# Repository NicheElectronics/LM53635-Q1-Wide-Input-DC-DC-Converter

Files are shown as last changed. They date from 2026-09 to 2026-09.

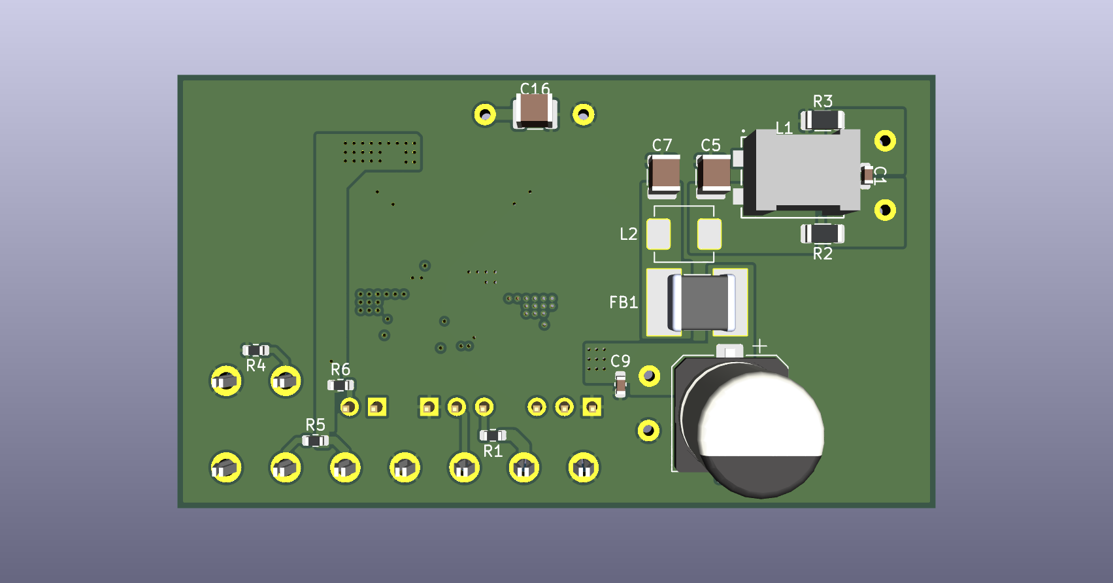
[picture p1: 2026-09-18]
pcb-design/renders/PCB-3D-Bottom.png

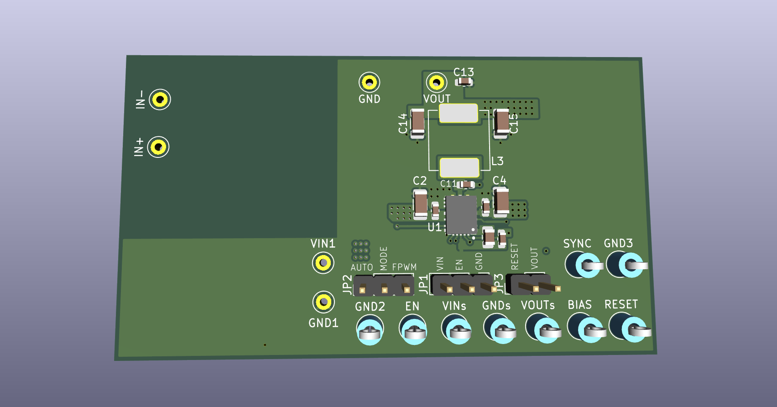
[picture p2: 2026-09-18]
pcb-design/renders/PCB-3D-Top.png

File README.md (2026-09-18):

# LM53635-Q1 Wide-Input DC-DC Converter

A four-layer, **5 V / 3.5 A design-target** synchronous buck converter built around the Texas Instruments **LM53635-Q1**. The board is intended for a **6–36 V input** and provides a choice of direct or EMI-filtered input paths for evaluating power-supply behavior.

> **Status:** PCB design and PSpice simulation are complete. The board has not yet been fabricated or electrically validated. The voltage, current, efficiency and EMI performance described here are design goals, not measured results.

## At a glance

| Item | Design |
| --- | --- |
| Controller | TI LM53635-Q1 automotive synchronous step-down converter |
| Intended input | 6–36 V DC |
| Intended output | 5 V, up to 3.5 A design target |
| PCB | Four layers, designed in KiCad |
| Input options | Direct path and EMI-filtered path |
| Analysis | PSpice startup and steady-state/transient simulations |
| Hardware verification | Pending fabrication and bench measurements |

The **6–36 V** range is this board's intended range. The IC's own operating limits and transient ratings are specified in the [TI LM53635-Q1 datasheet](https://www.ti.com/product/LM53635-Q1); they should not be treated as a measured rating of the assembled board.

## Design overview

```mermaid
flowchart LR
    VIN["6–36 V input"] --> PATH["Direct or filtered input"]
    PATH --> BUCK["LM53635-Q1 buck stage"]
    BUCK --> OUT["5 V output"]
```

The layout emphasizes a compact switching-current loop, local decoupling, sensible AGND/GND handling, input filtering and accessible measurement points. The filtered and direct input options support comparison during later EMI and transient testing. The project files include KiCad hardware data, manufacturing outputs, board renders and PSpice work; consult those source files for exact component values and connector pinouts.

## Simulation and validation

Startup and transient behavior have been examined in **PSpice for TI**. Simulation helps check the design before fabrication but does not establish hardware output ripple, efficiency, thermal behavior or emissions.

Once a board is assembled, the planned checks are:

1. Inspect assembly, polarity and resistance between each power rail and ground.
2. Power the board from a current-limited bench supply and verify the 5 V output at light load.
3. Check startup and output regulation across the intended input range and representative loads.
4. Measure ripple, load-transient response and component temperature; record the instruments and test conditions.
5. Compare direct and filtered input paths and evaluate conducted EMI with a suitable measurement setup.

No bench measurements or compliance results are claimed at this stage.

## Design files and reference

The repository contains the schematic, PCB design, manufacturing material, renders and simulation results. Use the **KiCad source files** as the authority for the actual revision and the [TI datasheet](https://www.ti.com/product/LM53635-Q1) for device limits and recommended layout practice.

## Author

**Nishant Patil**

No license has been specified for the project files. Add one if you want to define reuse terms.

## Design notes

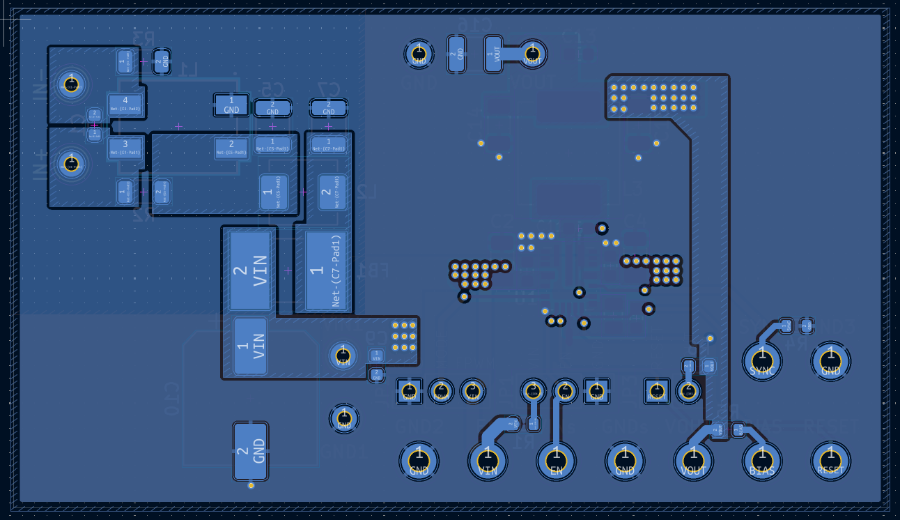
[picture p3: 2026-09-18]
pcb-design/layers/L4-Bottom-Power-Signal-GND-Pour.png

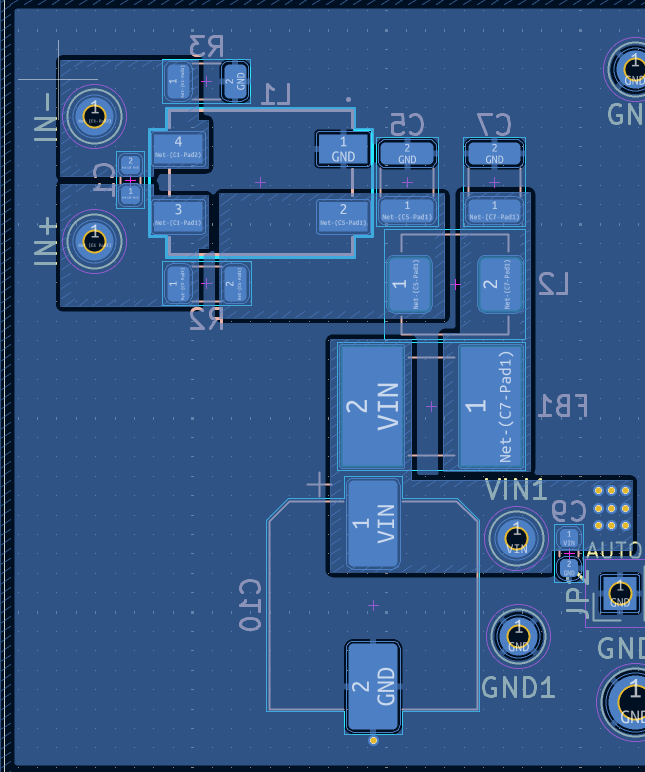
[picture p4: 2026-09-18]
pcb-design/emi-filter/EMI-Filter-PCB-Implementation.png

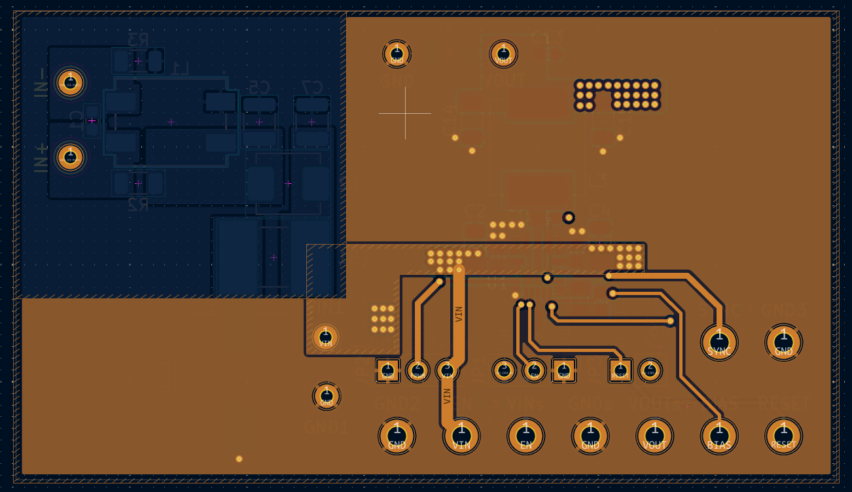
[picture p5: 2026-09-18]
pcb-design/layers/L3-Power-Signal-GND-Pour.png

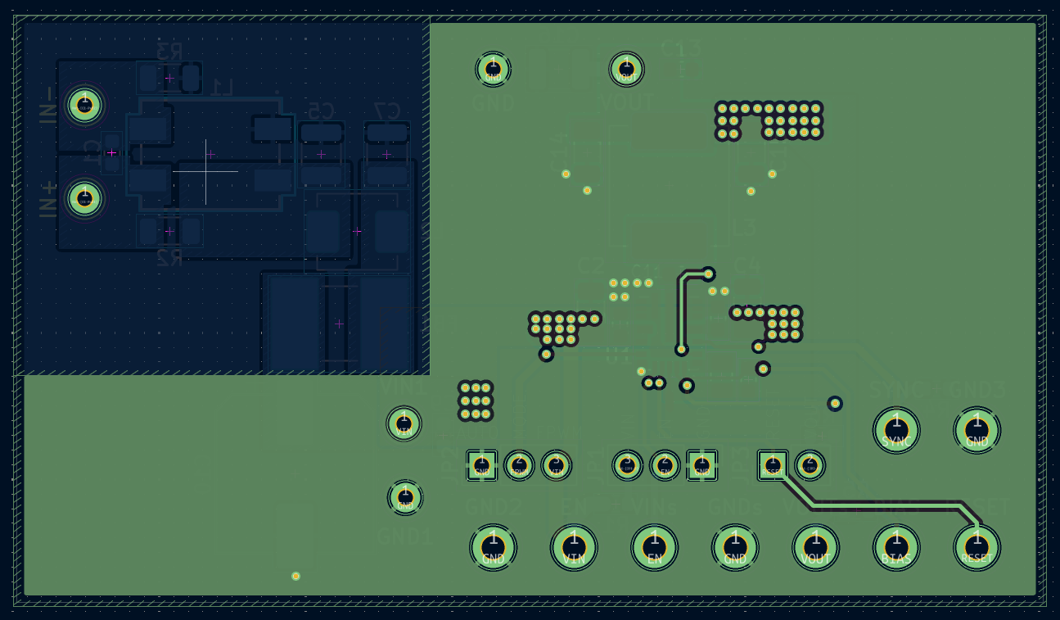
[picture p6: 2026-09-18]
pcb-design/layers/L2-GND-Plane-Local-Signals.png

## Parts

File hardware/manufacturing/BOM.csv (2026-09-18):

Reference | Qty | Value | DNP | Exclude from BOM | Exclude from Board | Footprint | Datasheet
BIAS1,EN1,GND2,GND3,GNDs1,RESET1,SYNC1,VINs1,VOUTs1 | 9 | TestPoint |  |  |  | TestPoint:TestPoint_Keystone_5005-5009_Compact | ~
C1,C9,C12,C13 | 4 | 0.1uF |  |  |  | Capacitor_SMD:C_0603_1608Metric | ~
C2,C4 | 2 | 10uF |  |  |  | Capacitor_SMD:C_1206_3216Metric | ~
C3,C6 | 2 | 0.047uF |  |  |  | Capacitor_SMD:C_0603_1608Metric | ~
C5,C7 | 2 | 4.7uF |  |  |  | Capacitor_SMD:C_1210_3225Metric | ~
C8 | 1 | 4.7uF |  |  |  | Capacitor_SMD:C_0805_2012Metric | ~
C10 | 1 | 100uF |  |  |  | Capacitor_SMD:CP_Elec_10x10.5
C11 | 1 | 0.47uF |  |  |  | Capacitor_SMD:C_0603_1608Metric | ~
C14,C15 | 2 | 22uF |  |  |  | Capacitor_SMD:C_1206_3216Metric | ~
C16 | 1 | 47uF |  |  |  | Capacitor_SMD:C_1210_3225Metric | ~
FB1 | 1 | 600 ohm |  |  |  | HI2220P601R-10:FB_HI2220P601R-10 | ~
GND1,GND4,IN+1,IN-1,VIN1,VOUT1 | 6 | TestPoint |  |  |  | TestPoint:TestPoint_Keystone_5000-5004_Miniature | ~
JP1 | 1 | EN Jumper |  | Excluded from BOM |  | Connector_PinHeader_2.54mm:PinHeader_1x03_P2.54mm_Vertical | ~
JP2 | 1 | FPWM Jumper |  | Excluded from BOM |  | Connector_PinHeader_2.54mm:PinHeader_1x03_P2.54mm_Vertical | ~
JP3 | 1 | Reset Jumper |  |  |  | Connector_PinHeader_2.54mm:PinHeader_1x02_P2.54mm_Vertical | ~
L1 | 1 | ACM9070-701-2PL-TL01 |  |  |  | ACM9070-701-2PL-TL01:IND_ACM9070_TDK | ACM9070-701-2PL-TL01
L2 | 1 | 2.2uH |  |  |  | IHLP2020CZER2R2M11:INDM5451X300N | ~
L3 | 1 | 2.2uH |  |  |  | IHLP3232DZER2R2M11:INDM8681X400N | ~
NT1 | 1 | NetTie_2 |  | Excluded from BOM |  | NetTie:NetTie-2_SMD_Pad0.5mm | ~
R1,R4,R6 | 3 | 100K |  |  |  | Resistor_SMD:R_0603_1608Metric | ~
R2,R3 | 2 | 0R |  |  |  | Resistor_SMD:R_1206_3216Metric | ~
R5 | 1 | 3R |  |  |  | Resistor_SMD:R_0603_1608Metric | ~
U1 | 1 | LM536353QRNLRQ1 |  |  |  | LM53635LQRNLTQ1:CONV_LMS3655MMRNLR | https://www.ti.com/lit/gpn/lm53635-q1

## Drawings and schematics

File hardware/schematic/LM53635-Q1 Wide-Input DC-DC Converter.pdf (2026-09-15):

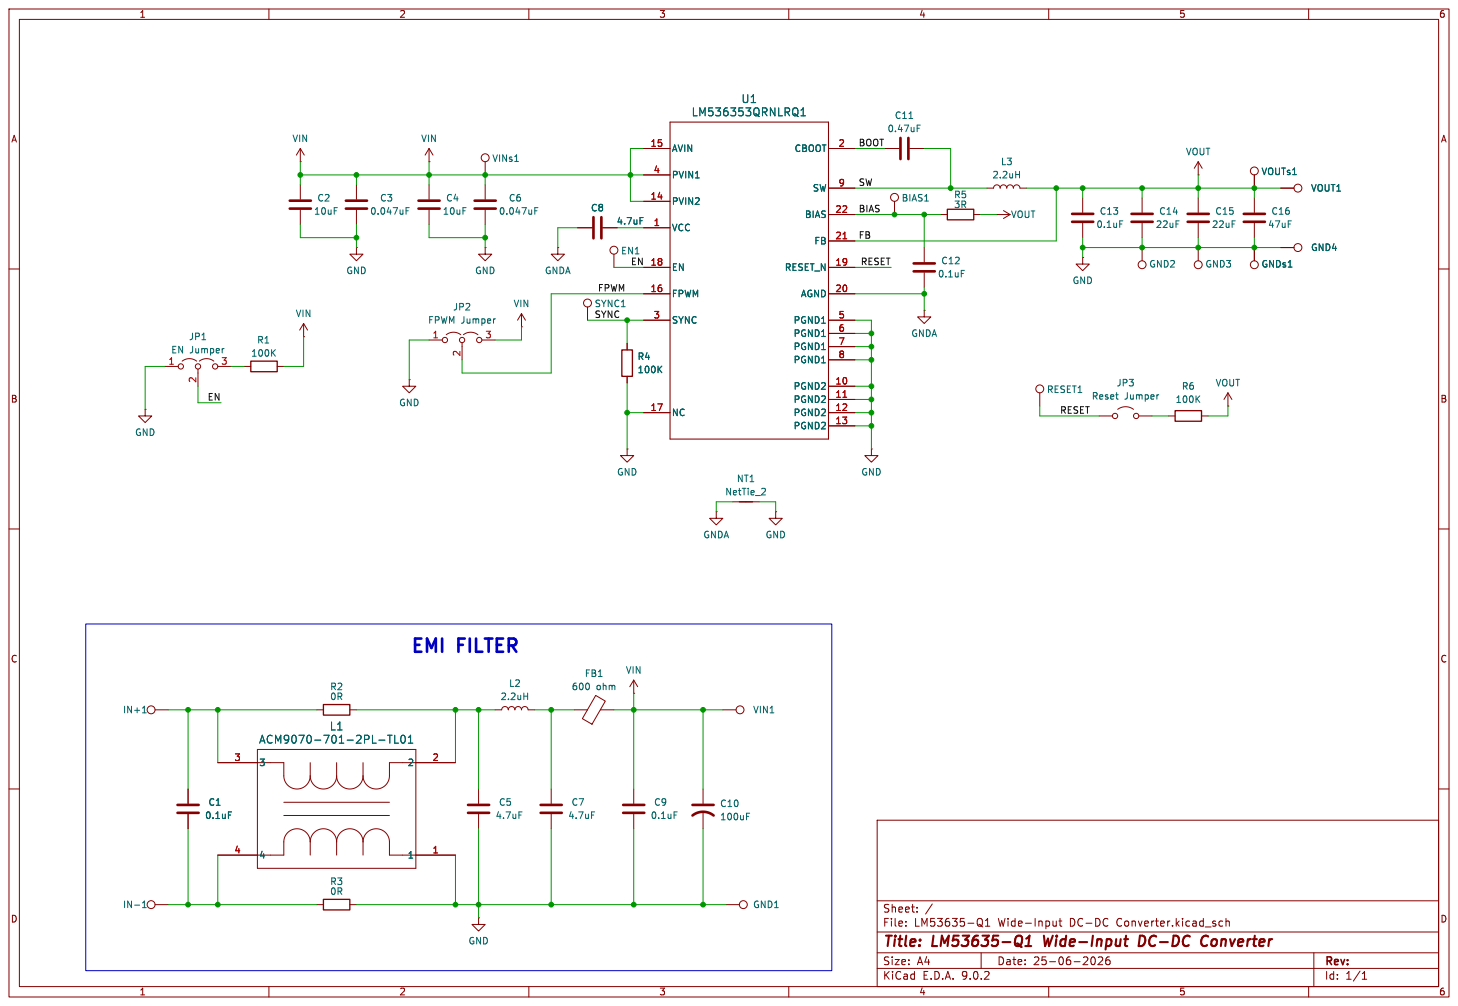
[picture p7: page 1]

BOOT SW EMI FILTER

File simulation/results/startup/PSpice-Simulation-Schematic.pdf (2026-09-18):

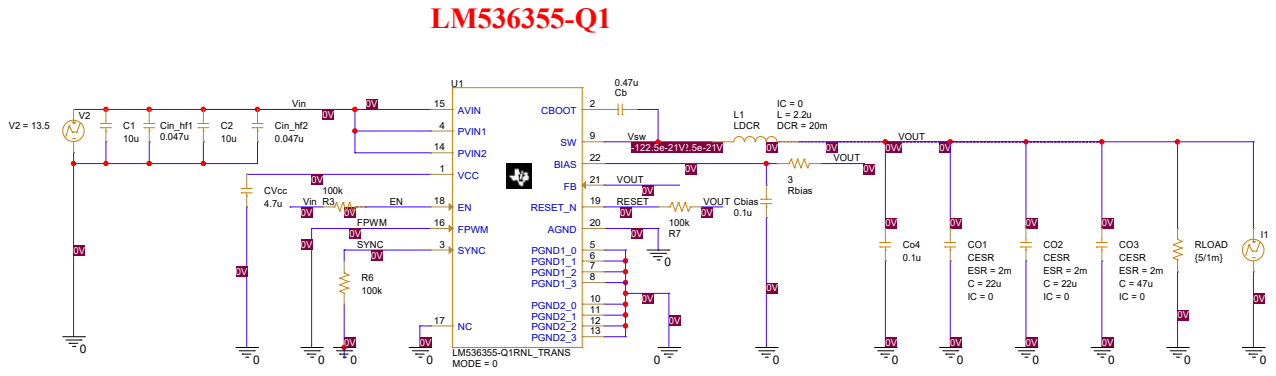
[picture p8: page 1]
FPWM 0V; SYNC 0V; Vsw -122.5e-21V; VOUT 0V; VOUT; Vin; RESET; Vin 0V; CO1 CESR; ESR = 2m C = 22u; Rbias 3 CVcc 4.7u; RLOAD; LM536355-Q1RNL_TRANS MODE = 0 VCC 1; CBOOT; 2 SYNC 3; PVIN1 4; PGND1_0; 5 PGND1_1; 6 PGND1_2; 7 PGND1_3; 9 PGND2_0; 10 PGND2_1; 11 PGND2_2; 12 PGND2_3; 13 PVIN2 14; AVIN 15; FPWM 16; RESET_N; 19 AGND; 21 BIAS; CO3 CESR; ESR = 2m C = 47u IC = 0; I1 Cin_hf1; CO2 CESR; IC = 0 Cbias 0.1u C2; Cin_hf2; L1 LDCR; L = 2.2u DCR = 20m

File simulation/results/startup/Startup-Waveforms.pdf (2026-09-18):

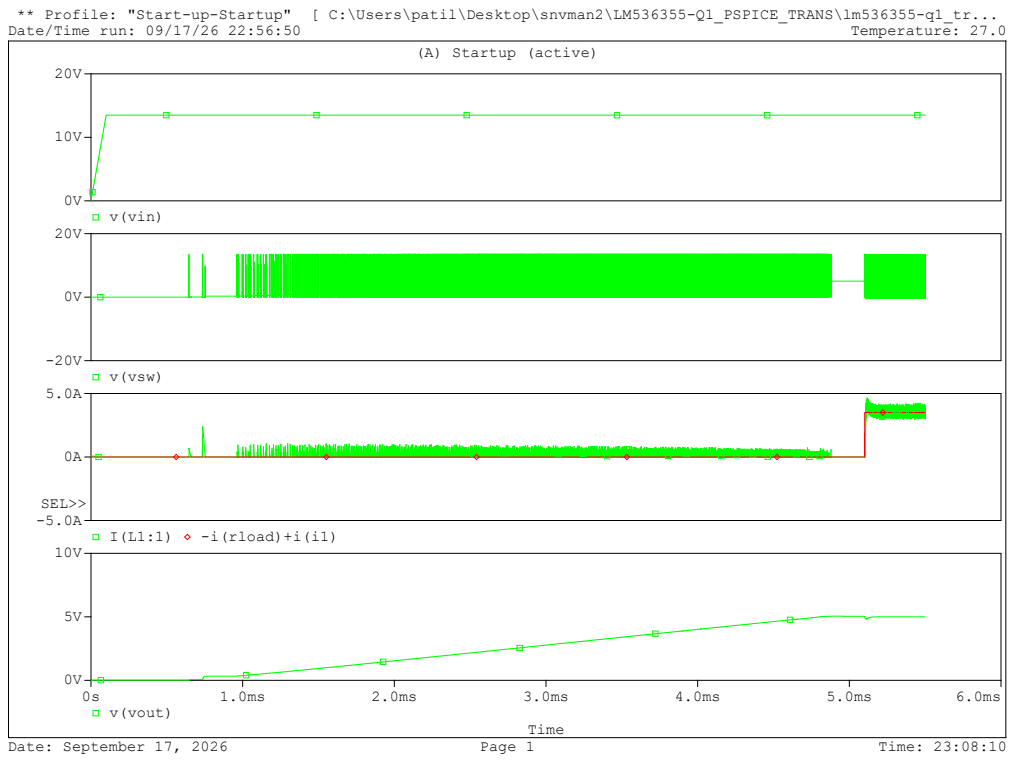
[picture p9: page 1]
Temperature: 27.0; Date: September 17, 2026; Page 1; Time: 23:08:10; (A) Startup (active); Time; v(vout); -i(rload)+i(i1); SEL>>; v(vsw); v(vin)

** Profile: "Start-up-Startup" [ C:\Users\patil\Desktop\snvman2\LM536355-Q1_PSPICE_TRANS\lm536355-q1_tr...
Date/Time run: 09/17/26 22:56:50

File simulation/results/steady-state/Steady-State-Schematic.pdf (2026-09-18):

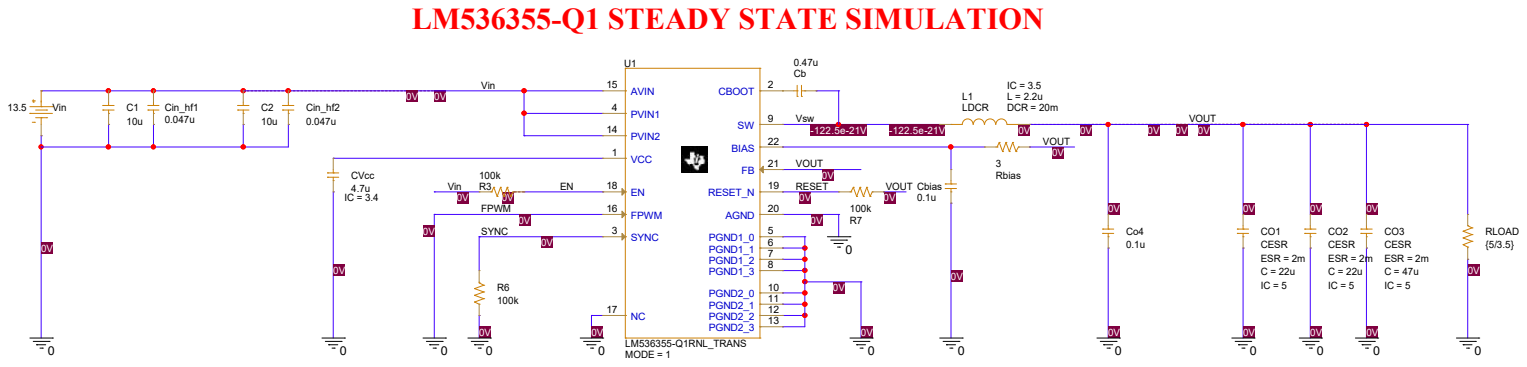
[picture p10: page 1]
FPWM; SYNC; Vsw -122.5e-21V; VOUT 0V; VOUT; 0V RESET 0V; Vin; Vin 0V; LM536355-Q1 STEADY STATE SIMULATION; CO1 CESR; ESR = 2m C = 22u; IC = 5 Cbias 0.1u Cin_hf1; LM536355-Q1RNL_TRANS MODE = 1 VCC 1; CBOOT; 2 SYNC 3; PVIN1 4; PGND1_0; 5 PGND1_1; 6 PGND1_2; 7 PGND1_3; 9 PGND2_0; 10 PGND2_1; 11 PGND2_2; 12 PGND2_3; 13 PVIN2 14; AVIN 15; FPWM 16; RESET_N; 19 AGND; 21 BIAS; Rbias 3 C1; CO2 CESR; 100k Cin_hf2; CVcc 4.7u; CO3 CESR; ESR = 2m C = 47u; LDCR; L = 2.2u DCR = 20m; RLOAD

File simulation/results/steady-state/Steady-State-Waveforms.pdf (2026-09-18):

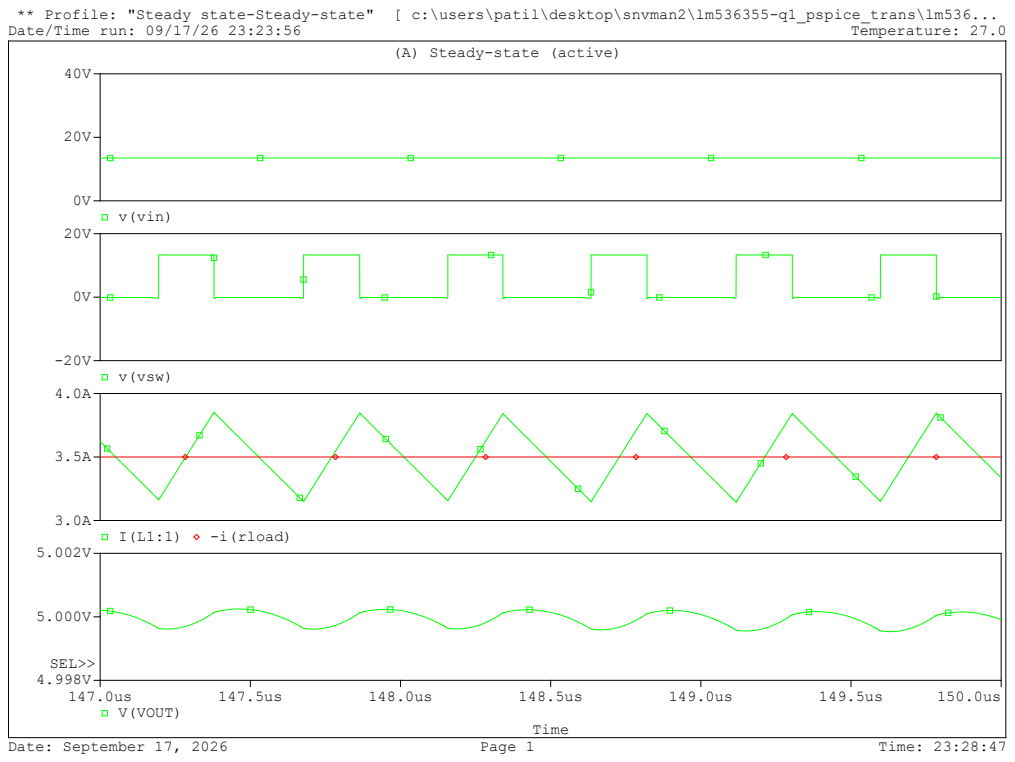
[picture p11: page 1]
Temperature: 27.0; Date: September 17, 2026; Page 1; Time: 23:28:47; Time; V(VOUT); SEL>>; -i(rload); v(vsw); v(vin)

** Profile: "Steady state-Steady-state" [ c:\users\patil\desktop\snvman2\lm536355-q1_pspice_trans\lm536...
Date/Time run: 09/17/26 23:23:56

(A) Steady-state (active)

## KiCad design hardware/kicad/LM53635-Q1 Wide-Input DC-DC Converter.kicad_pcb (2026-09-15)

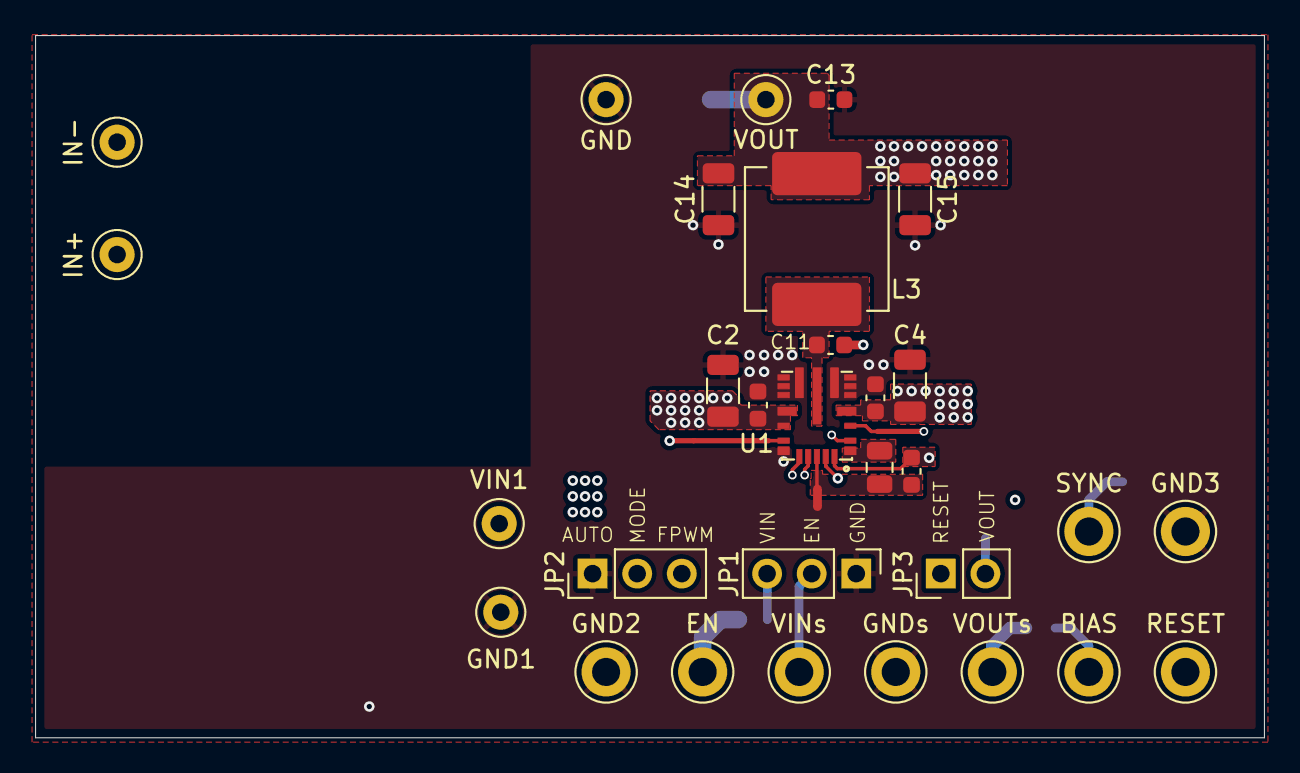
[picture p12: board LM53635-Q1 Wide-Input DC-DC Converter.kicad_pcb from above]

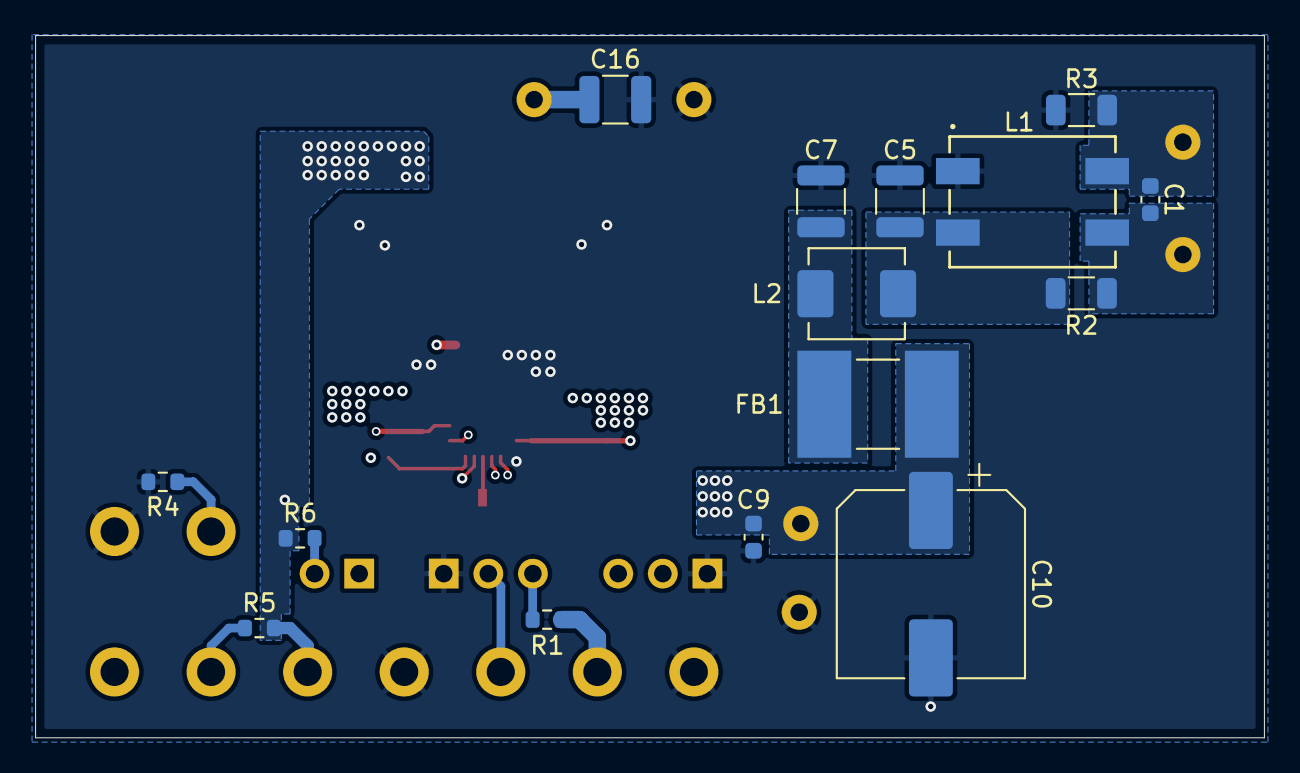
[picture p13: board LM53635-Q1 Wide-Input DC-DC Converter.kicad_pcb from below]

Board: 4 copper layers, 70.0 x 40.0 mm, 46 parts (15 on the bottom side), 18 nets.

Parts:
BIAS: TestPoint; TestPoint_Keystone_5005-5009_Compact
C1, C9, C12, C13: 0.1uF; C_0603_1608Metric
C2, C4: 10uF; C_1206_3216Metric
C3, C6: 0.047uF; C_0603_1608Metric
C5, C7: 4.7uF; C_1210_3225Metric
C8: 4.7uF; C_0805_2012Metric
C10: 100uF; CP_Elec_10x10.5
C11: 0.47uF; C_0603_1608Metric
C14, C15: 22uF; C_1206_3216Metric
C16: 47uF; C_1210_3225Metric
EN: TestPoint; TestPoint_Keystone_5005-5009_Compact
FB1: 600 ohm; FB_HI2220P601R-10
GND, GND1: TestPoint; TestPoint_Keystone_5000-5004_Miniature
GND2, GND3: TestPoint; TestPoint_Keystone_5005-5009_Compact
GNDs: TestPoint; TestPoint_Keystone_5005-5009_Compact
IN+: TestPoint; TestPoint_Keystone_5000-5004_Miniature
IN-: TestPoint; TestPoint_Keystone_5000-5004_Miniature
JP1: EN Jumper; PinHeader_1x03_P2.54mm_Vertical
JP2: FPWM Jumper; PinHeader_1x03_P2.54mm_Vertical
JP3: Reset Jumper; PinHeader_1x02_P2.54mm_Vertical
L1: ACM9070-701-2PL-TL01; IND_ACM9070_TDK
L2: 2.2uH; INDM5451X300N
L3: 2.2uH; INDM8681X400N
NT1: NetTie_2; NetTie-2_SMD_Pad0.5mm
R1, R4, R6: 100K; R_0603_1608Metric
R2, R3: 0R; R_1206_3216Metric
R5: 3R; R_0603_1608Metric
RESET: TestPoint; TestPoint_Keystone_5005-5009_Compact
SYNC: TestPoint; TestPoint_Keystone_5005-5009_Compact
U1: LM536353QRNLRQ1; CONV_LMS3655MMRNLR
VIN1: TestPoint; TestPoint_Keystone_5000-5004_Miniature
VINs: TestPoint; TestPoint_Keystone_5005-5009_Compact
VOUT: TestPoint; TestPoint_Keystone_5000-5004_Miniature
VOUTs: TestPoint; TestPoint_Keystone_5005-5009_Compact

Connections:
/BIAS: BIAS.1, C12.1, R5.1, U1.22 (BIAS)
/BOOT: C11.1, U1.2 (CBOOT)
/EN: JP1.2 (C), U1.18 (EN), VINs.1
/FPWM: JP2.2 (C), U1.16 (FPWM)
/RESET: JP3.1 (A), RESET.1, U1.19 (RESET_N)
/SW: C11.2, L3.1, U1.9 (SW)
/SYNC: R4.1, SYNC.1, U1.3 (SYNC)
GND: C2.2, C3.2, C4.2, C5.2, C6.2, C7.2, C9.2, C10.2, C13.2, C14.2, C15.2, C16.2, GND.1, GND1.1, GND2.1, GND3.1, GNDs.1, JP1.1 (A), JP2.1 (A), L1.1, NT1.2, R3.2, R4.2, U1.5 (PGND1), U1.6 (PGND1), U1.7 (PGND1), U1.8 (PGND1), U1.10 (PGND2), U1.11 (PGND2), U1.12 (PGND2), U1.13 (PGND2), U1.17 (NC)
GNDA: C8.1, C12.2, NT1.1, U1.20 (AGND)
unnamed: C1.1, IN+.1, L1.3, R2.1
unnamed: C1.2, IN-.1, L1.4, R3.1
unnamed: C5.1, L1.2, L2.1, R2.2
unnamed: C7.1, FB1.1, L2.2
unnamed: JP1.3 (B), R1.1
unnamed: JP3.2 (B), R6.2
unnamed: C8.2, U1.1 (VCC)
VIN: C2.1, C3.1, C4.1, C6.1, C9.1, C10.1, EN.1, FB1.2, JP2.3 (B), R1.2, U1.4 (PVIN1), U1.14 (PVIN2), U1.15 (AVIN), VIN1.1
VOUT: C13.1, C14.1, C15.1, C16.1, L3.2, R5.2, R6.1, U1.21 (FB), VOUT.1, VOUTs.1

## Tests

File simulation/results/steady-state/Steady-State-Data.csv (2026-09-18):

Time | V(VOUT) | I(L1:1) | -i(rload) | v(vsw) | v(vin)
1.470000000004e-04 | 5.000208578792e+00 | 3.621549696606e+00 | 3.500146005155e+00 | -1.060230125853e-01 | 1.350000000000e+01
1.470017970805e-04 | 5.000207890877e+00 | 3.617319650907e+00 | 3.500145523614e+00 | -1.059020623214e-01 | 1.350000000000e+01
1.470053912406e-04 | 5.000206300544e+00 | 3.608859964022e+00 | 3.500144410380e+00 | -1.056601729268e-01 | 1.350000000000e+01
1.470125795607e-04 | 5.000202094614e+00 | 3.591942533742e+00 | 3.500141466230e+00 | -1.051764483066e-01 | 1.350000000000e+01
1.470269562010e-04 | 5.000189479681e+00 | 3.558115722463e+00 | 3.500132635777e+00 | -1.042092236771e-01 | 1.350000000000e+01
1.470416621570e-04 | 5.000170796956e+00 | 3.523525255032e+00 | 3.500119557869e+00 | -1.032201557178e-01 | 1.350000000000e+01
1.470547409062e-04 | 5.000149304638e+00 | 3.492771755384e+00 | 3.500104513246e+00 | -1.023407938944e-01 | 1.350000000000e+01
1.470656783585e-04 | 5.000127828894e+00 | 3.467060246437e+00 | 3.500089480226e+00 | -1.016055970571e-01 | 1.350000000000e+01
1.470752791767e-04 | 5.000106363315e+00 | 3.444496076942e+00 | 3.500074454321e+00 | -1.009603916638e-01 | 1.350000000000e+01
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
